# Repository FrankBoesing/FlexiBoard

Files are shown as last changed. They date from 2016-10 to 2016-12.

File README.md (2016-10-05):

# FlexiBoard

##Board for Teensy 3.2, 3.5, 3.6

https://forum.pjrc.com/threads/36869-T3-x-Flexiboard(-)

Link to board @ PCBs.io: https://pcbs.io/search?query=flexiboard
### License

<br />This work is licensed under a <a rel="license" href="http://creativecommons.org/licenses/by-sa/4.0/">Creative Commons Attribution-ShareAlike 4.0 International License</a>.

### Some Pictures
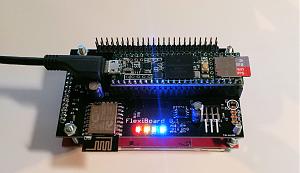
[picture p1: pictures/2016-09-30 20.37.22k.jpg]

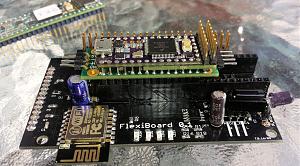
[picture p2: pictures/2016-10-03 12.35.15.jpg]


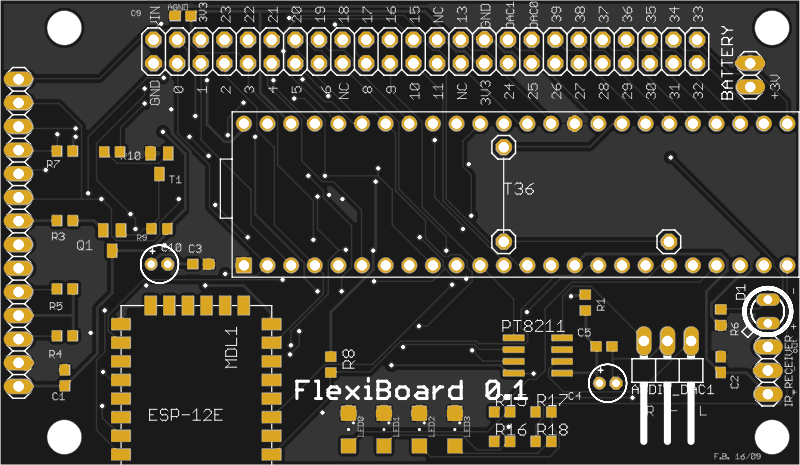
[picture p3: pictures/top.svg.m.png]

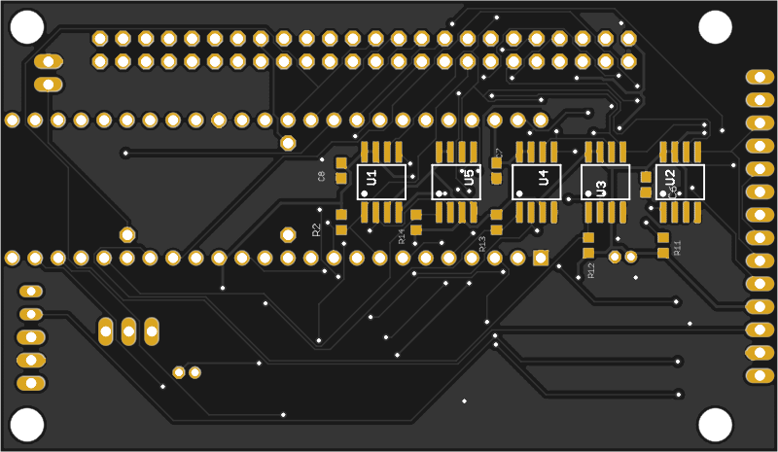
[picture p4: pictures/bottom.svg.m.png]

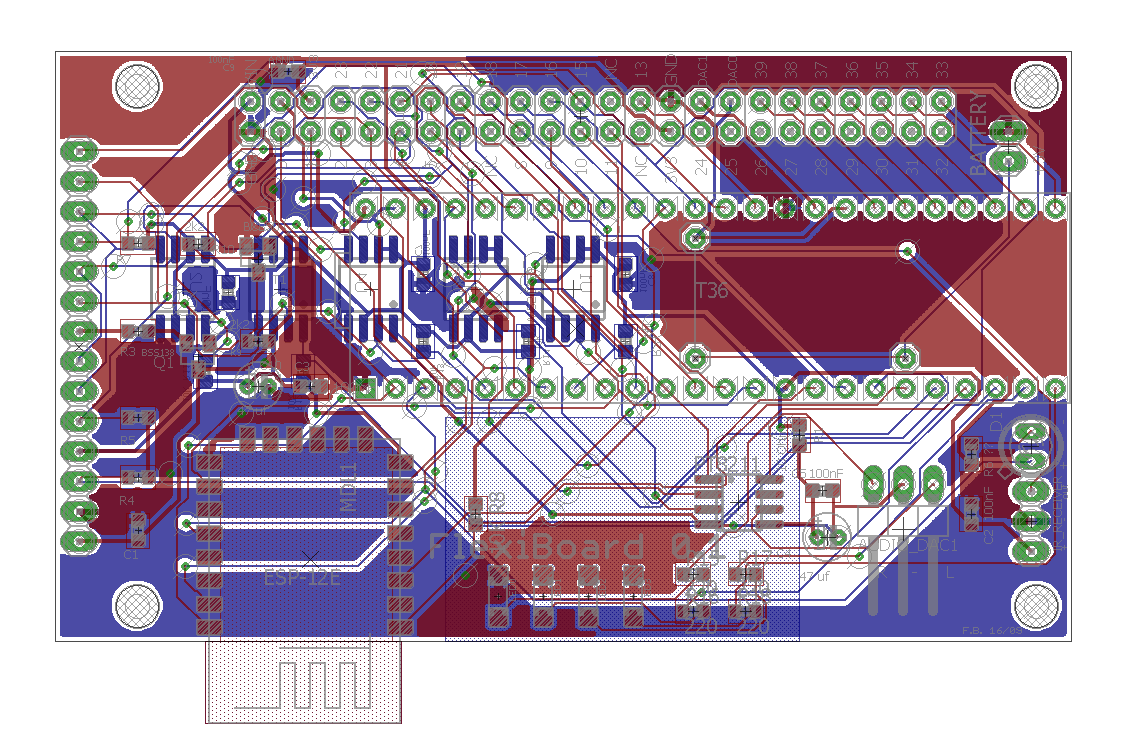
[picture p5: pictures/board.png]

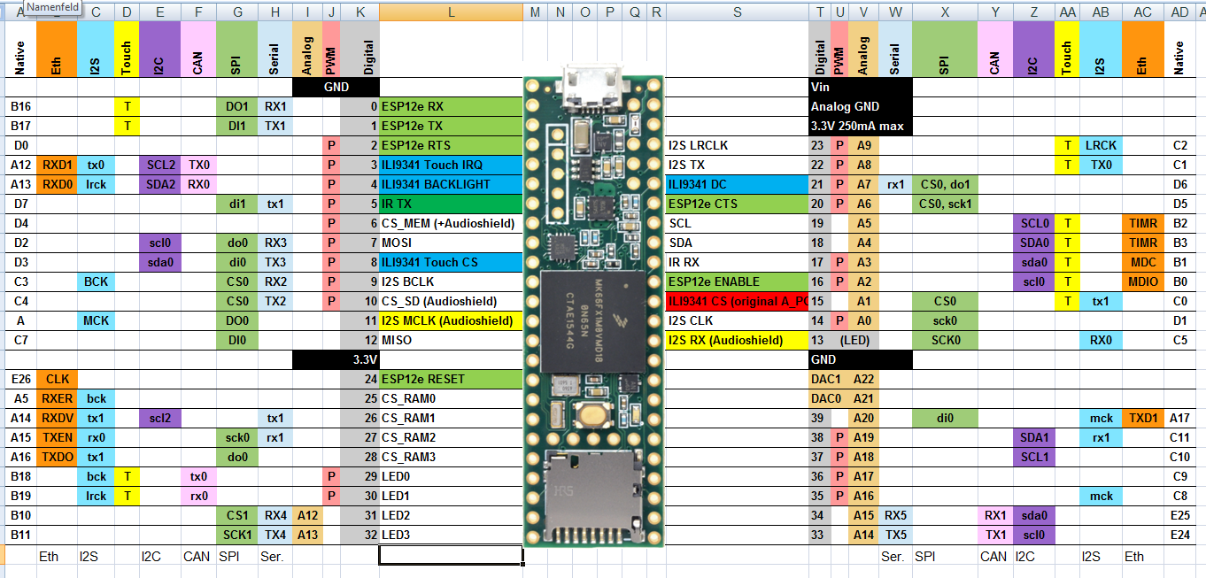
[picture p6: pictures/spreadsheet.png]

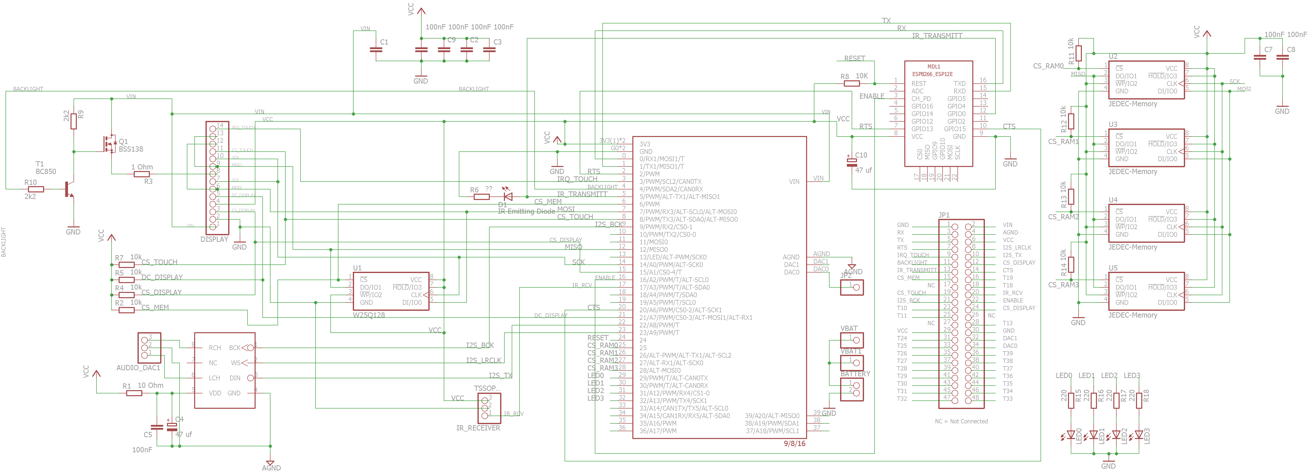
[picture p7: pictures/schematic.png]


## FLASH ESP FIRMWARE

### Flash size 32Mbit: 512KB+512KB
    boot_v1.2+.bin              0x00000
    user1.1024.new.2.bin        0x01000
    esp_init_data_default.bin   0x3fc000 (optional)
    blank.bin                   0x7e000 & 0x3fe000

## Flash Firmware

1. Extract the Firmware and Flash-Tool in extras/ESP8266/Firmware.zip

2. Start ESP8266Flasher.exe and configure it :

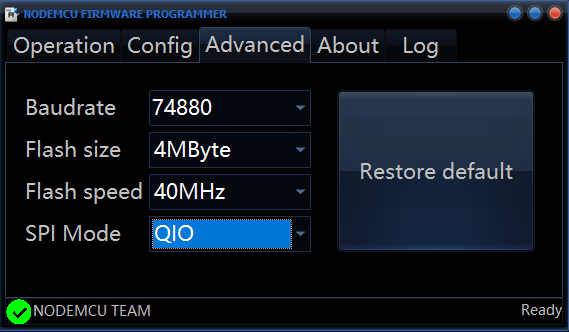
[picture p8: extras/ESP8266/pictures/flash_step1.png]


Select the files to upload (from the zip-file):

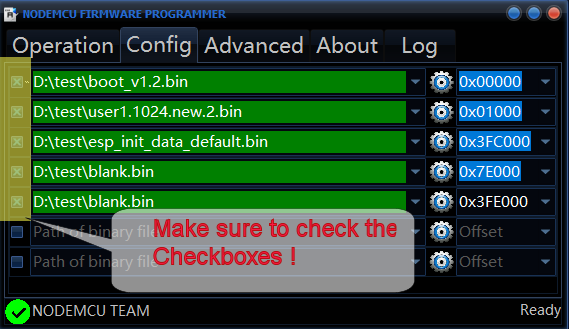
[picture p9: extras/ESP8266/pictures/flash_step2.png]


Load FlexiBoard_FlashESP8266.ino to the Teensy

Select the COM-Port:

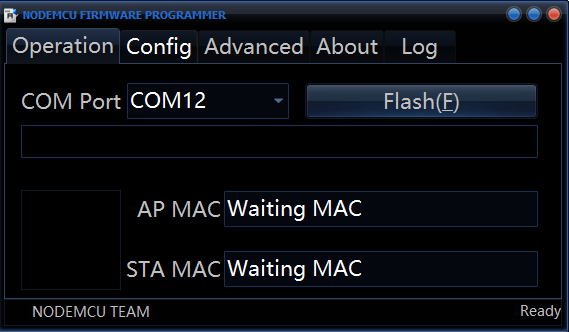
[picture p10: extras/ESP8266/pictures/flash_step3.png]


Reset the Teensy and click the "Flash" button

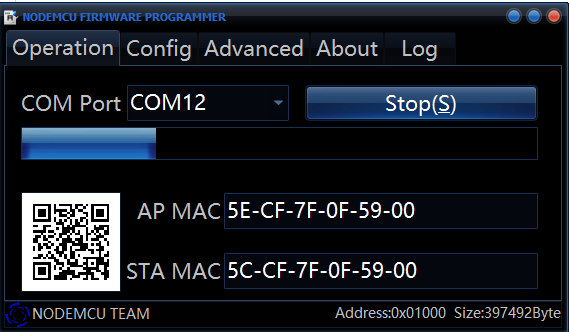
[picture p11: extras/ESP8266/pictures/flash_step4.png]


After that, you can run FlexiBoard_TalkToESP8266.ino and enter the following commands into the console to update the ESP8266-Firmware:

## Update Firmware

1.Start FlexiBoard_TalkToESP8266.ino example and select CR+LF as lineendings in the terminal.

2.Make sure the ESP is in sta or sta+ap mode

    AT+CWMODE=3
    OK

3.Make sure it got the ip address

    AT+CWJAP="YourSSID","YourWLANPassword"
    OK
    
    AT+CIFSR
    192.168.1.134

4.Let's update

    AT+CIUPDATE
    +CIPUPDATE:1    found server
    +CIPUPDATE:2    connect server
    +CIPUPDATE:3    got edition
    +CIPUPDATE:4    start start
    
    OK

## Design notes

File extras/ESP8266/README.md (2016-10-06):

#Using Arduino for ESP

- Upload the FlexiBoard_FlashESP8266 example to the Teensy

- Enter http://arduino.esp8266.com/stable/package_esp8266com_index.json into Additional Board Manager URLs field. 

- Open Boards Manager from Tools > Board menu and install esp8266 platform (and don't forget to select your ESP8266 board from Tools > Board menu after installation).

- Select the following options from the Arduino-Menu:

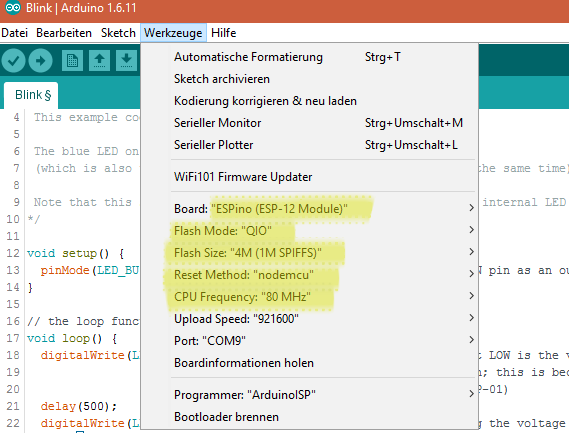
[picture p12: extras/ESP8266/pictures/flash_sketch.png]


- Try the BLINK-Example from the Examples / ESP8266 Menu

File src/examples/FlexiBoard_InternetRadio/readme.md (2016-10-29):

Minimal Internetradio
===

This is a minimal webradio. It is in no way complete.
In can play 44.1KHz - MP3 radio streams.

It works best, if you add (min) 2 pcs 23LC1024 RAMS (or more).
But i can be run with the Teensy 3.5/3.6 RAM only, too. 
In this case, 128KB internal RAM are used. This is a bit too less, so 
expect some problems, if your internet-connection is not good.

Currently, it connects to a German station - you may want to edit that, and use
a local station for a better connection.

Setup
===

For a better experience, edit _Serial1.c_ from the Teensy-core and set 
RX_BUFFER_SIZE     2048

Use the Example "TalkToESP" to setup the ESP:

First, restore the factory-settings:
- AT+RESTORE

Set station mode:
- AT+CWMODE_DEF=1

Store the connection to your WLAN
- AT+CWJAP_DEF ="SSID", "PASSWORD"

Additional libraries needed: 
https://github.com/FrankBoesing/Teensy-MP3

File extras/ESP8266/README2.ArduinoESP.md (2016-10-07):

Posted details here from :: https://forum.pjrc.com/threads/36869-T3-x-Flexiboard(-)?p=117701&viewfull=1#post117701

HOW TO GET ESP PROGRAMMED OTA WITH A very functional WEBSERVER THROUGH ARDUINO::
I'd say start with IDE 1.6.12 it works for me.

Get Server code from here: https://github.com/nailbuster/myWebServer
It says to get these two things to your sketchbook/libraries folder:
- TimeLib for ntp here: https://github.com/PaulStoffregen/Time
- Arduino Json here: https://github.com/bblanchon/ArduinoJson 

Get the ESP Arduino code from here: https://github.com/esp8266/Arduino

Use Boards Manager and the JSON from there: 
Boards manager link: http://arduino.esp8266.com/stable/pa...com_index.json 

By default OTA is OFF! - it won't show this used "ArduinoOTA"
Find this code on your machine where you put it in libraries and uncomment this line >> //#define ALLOW_IDEOTA
https://github.com/nailbuster/myWebServer/blob/master/myWebServer.h#L48
- OTA is "unsafe" so it is off by default :: - [there is a new scheme to password protect OTA updates - otherwise anyone who can see the WiFi name can program it.] :: https://github.com/esp8266/Arduino/blob/master/doc/ota_updates/readme.md#password-protection
- OTA requires PYTHON_2.7 to be installed ON THE PATH :: https://github.com/esp8266/Arduino/blob/master/doc/ota_updates/readme.md#application-example

If you do that and compile "sketchbook...\libraries\myWebServer\examples\myWe bServerSample" it should show those libraries like this::

- Using library ESP8266WiFi at version 1.0 in folder: C:\Users\YOU\AppData\Local\Arduino15\packages\esp8 266\hardware\esp8266\2.3.0\libraries\ESP8266WiFi 
- Using library ESP8266WebServer at version 1.0 in folder: C:\Users\YOU\AppData\Local\Arduino15\packages\esp8 266\hardware\esp8266\2.3.0\libraries\ESP8266WebSer ver 
- Using library ESP8266mDNS in folder: C:\Users\YOU\AppData\Local\Arduino15\packages\esp8 266\hardware\esp8266\2.3.0\libraries\ESP8266mDNS (legacy)
- Using library DNSServer at version 1.1.0 in folder: C:\Users\YOU\AppData\Local\Arduino15\packages\esp8 266\hardware\esp8266\2.3.0\libraries\DNSServer 
- Using library ArduinoOTA at version 1.0 in folder: C:\Users\YOU\AppData\Local\Arduino15\packages\esp8 266\hardware\esp8266\2.3.0\libraries\ArduinoOTA 
- Using library ArduinoJson at version 5.1.0 in folder: i:\tcode\libraries\ArduinoJson 
- Using library myWebServer at version 1.0.1 in folder: i:\tcode\libraries\myWebServer 
- Using library Time at version 1.5 in folder: i:\tcode\libraries\Time 

The first time upload you'll have to push over serially of course. 
From then on - if you don't add faulting code you can do OTA updates about 5 times faster than Serial. As noted I set up an ESP read pin that is set to indicate ABORT USER CODE (by Teensy or wire) and just allow ther server code to run and do OTA. It is easy to touch something (IN ERROR) and HANG an ESP because it is doing DISK and WIFI stuff - if you repower with that bit set - it will wait for a fresh OTA upload. I think this is on my GitHub too. << I could post my sketches but they are hacked to accommodate 4 different ESP's and their different configurations to the Teensy/onehorse_FC_3.2 units - after 6 months I don't under stand them again myself yet. And they would not match the Flexiboard - but I might post something as it was quite fun and usable.>>

>> For starters I would suggest using 4MB with 3 MB SPIFFS - 1MB for code is good, 3MB for SPIFFS is better. My sketch is 311KB. Using of near HALF of 1MB still allows OTA FLASH - you can change later if you want that much code. This WEBSERVER library runs all HTML pages for the server from SPIFFS - You can Read Write other data there too when you don't need to put it in FLASH - the upload is smaller faster.

Get your Server IP address and his :: 192.168.1. _??_ /wifisetup.html, there is a .gz file there it runs from, you can NAME the device and that will show on the IDE then.
<<Yes the server has code to perform GZ decompress to some degree on files to run them! Details on the server github - I asked a question in an ISSUE>>

- WARNING - WARNING - WARNING !!!!
- I just wiped my 3MB SPIFFS DATA - when you enter the IDE ALWAYS CHECK the TOOLS :: SPIFFS size and other params - the IDE will often not remember some of those CRITICAL things properly across board changes!!!!!
- I just found this out the hard way for the first time - so that lets me show the details above because my ESP is TRASHED - 512K Code and 64K SPIFFS is the DEFAULT !!!!!
- WARNING - WARNING - WARNING !!!!
So I lost my SPIFFS data - my network configuration setting and I cannot OTA upload because 512MB cannot fit two copies of the 311K sketch !!!!
I'll have to get the details right to T_3.2 proxy upload again from my hacked sketch ...

ONE MORE MISSING PIECE :: 
- You can just transfer files over FTP once the server is running - THAT IS WAY COOL!!
- You may want SPIFFS IMAGE data on your device 
My github refers to this :: you make a folder image and then upload the data to it. 
https://github.com/esp8266/arduino-esp8266fs-plugin/releases/tag/0.2.0

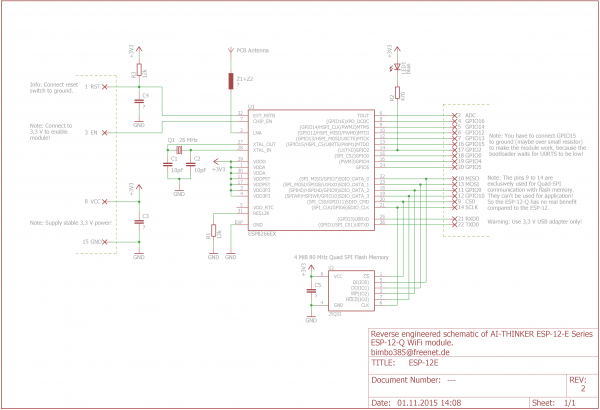
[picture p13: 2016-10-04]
extras/ESP8266/schematic_esp-12e.png

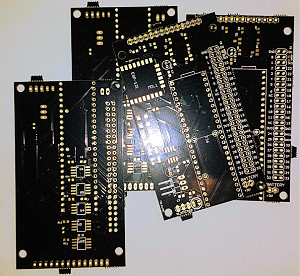
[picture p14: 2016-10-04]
pictures/2016-10-01 16.12.59k.png

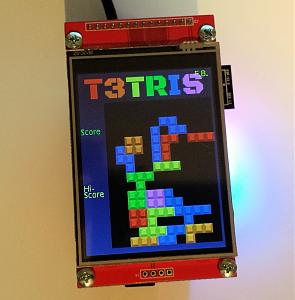
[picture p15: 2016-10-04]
pictures/2016-09-30 20.38.55k.jpg

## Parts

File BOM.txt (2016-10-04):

Partlist

Part        Value              Device                    Package

Mount all:
C1          100nF              C-EUC0603                 C0603
C2          100nF              C-EUC0603                 C0603
C3          100nF              C-EUC0603                 C0603
C5          100nF              C-EUC0603                 C0603
C6          100nF              C-EUC0603                 C0603
C7          100nF              C-EUC0603                 C0603
C8          100nF              C-EUC0603                 C0603
C9          100nF              C-EUC0603                 C0603

WLAN
=====
ESP8266-ESP12E
C10         220 uf             CPOL-EUE1.8-4             E1,8-4
R8          10K                R-EU_R0603                R0603

AUDIO
=======
PT8211      PT8211SO8          PT8211SO8                 SO8
AUDIO_DAC1                     PINHD-1X3/90              1X03/90
C4          47 uf              CPOL-EUE1.8-4             E1,8-4
R1          10 Ohm             R-EU_R0603                R0603

MEMORY
======
For example RAM 23LC1024 or Flash W25Q128

U1          JEDEC-Memory       				 SOIC-8
U2          JEDEC-Memory
U3          JEDEC-Memory
U4          JEDEC-Memory
U5          JEDEC-Memory
R2          10k                R-EU_R0603                R0603
R11         10k                R-EU_R0603                R0603
R12         10k                R-EU_R0603                R0603
R13         10k                R-EU_R0603                R0603
R14         10k                R-EU_R0603                R0603

IR RECEIVE
==========
For example TSOP1136 or many others.
IR_RECEIVER TSOP..             PINHD-1X3                 1X03

IR SEND
==========
D1          IR Emitting Diode  ????                      ????
R6          100                R-EU_R0603                R0603

VBAT:
=====
VBAT                           PINHD-1X1                 1X01
VBAT1                          PINHD-1X1                 1X01
BATTERY                        PINHD-1X2                 1X02

LED:
======

LED0                           LEDSML1206                SML1206
LED1                           LEDSML1206                SML1206
LED2                           LEDSML1206                SML1206
LED3                           LEDSML1206                SML1206
R15         330 Ohm            R-EU_R0603                R0603
R16         330 Ohm            R-EU_R0603                R0603
R17         330 Ohm            R-EU_R0603                R0603
R18         330 Ohm            R-EU_R0603                R0603

DISPLAY
=======
ILI9341 with touch

T1          BC850              BC850                     SOT23
Q1          BSS138             BSS123                    SOT23
R3          10 Ohm             R-EU_R0603                R0603
R4          10k                R-EU_R0603                R0603

R5          10k                R-EU_R0603                R0603

R7          10k                R-EU_R0603                R0603
R9          1k                 R-EU_R0603                R0603
R10         1k                 R-EU_R0603                R0603
DISPLAY                        PINHD-1X14                1X14

JP1                            PINHD-2X24                2X24

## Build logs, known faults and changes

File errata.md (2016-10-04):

#Errata:
- Wrong location for Teensy 3.1/3.2 VBAT/DAC0 Pins (still possible to use them with a bit fiddling.. or use Teesy 3.5/3.6)
- Due to an error, pins 24-32 are not routed to the 48-Pin-connector :-( FIX: Patch them on the backside.
- Limited IR-Send power, but works for distances ~2m. For more power, add a (extern) transistor.
- The connector for the IR-Receiver is + - OUT, but most IR -Receivers use - + OUT Fix: Do not mount directly and use a cable

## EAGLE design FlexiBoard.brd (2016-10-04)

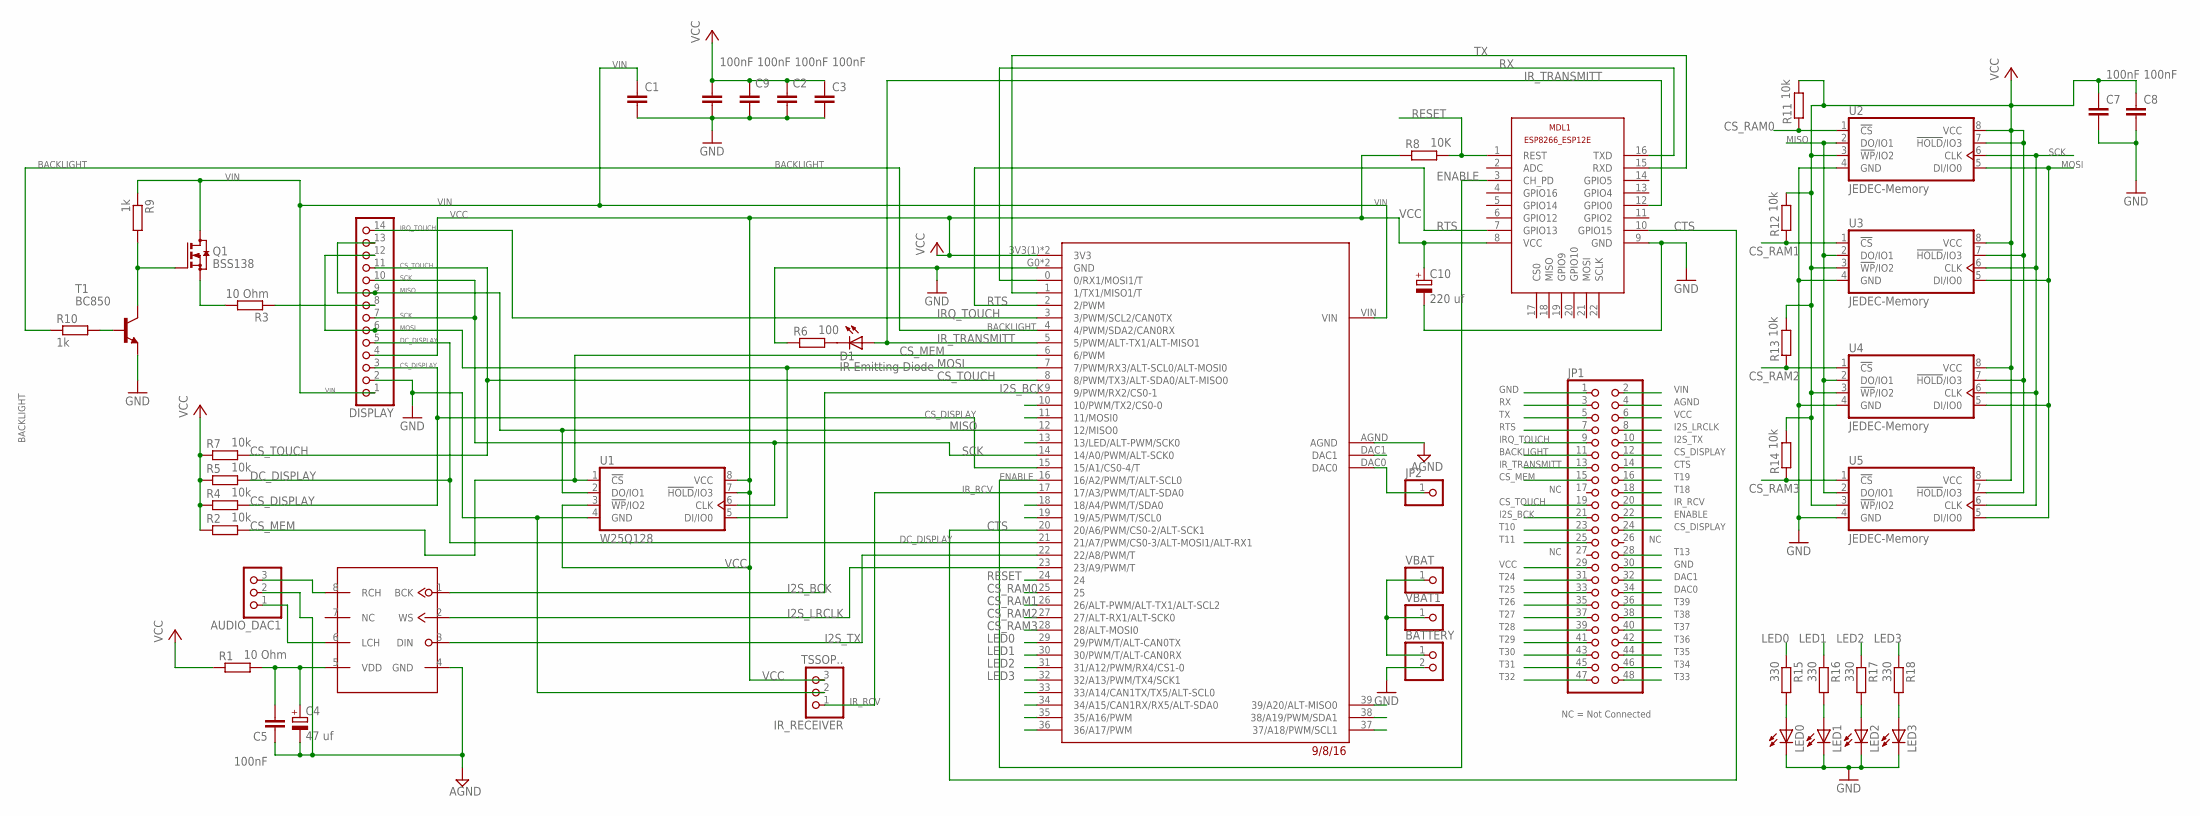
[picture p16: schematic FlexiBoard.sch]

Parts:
AUDIO_DAC1: PINHD-1X3/90; 1X03/90
BATTERY: PINHD-1X2; 1X02
C1, C2, C3, C5, C6, C7, C8, C9: 100nF; C0603
C4: 47 uf; E1,8-4
C10: 220 uf; E1,8-4
D1: IR Emitting Diode; SFH482
DISPLAY: PINHD-1X14; 1X14
IR_RECEIVER: TSSOP..; 1X03
JP1: PINHD-2X24; 2X24
JP2: PINHD-1X1; 1X01
LED0, LED1, LED2, LED3: LEDSML1206; SML1206
MDL1: ESP8266-12EESP8266-ESP12E; ESP8266-ESP12E
PT8211: PT8211SO8; SO8
Q1: BSS138; SOT23
R1, R3: 10 Ohm; R0603
R2, R4, R5, R7, R11, R12, R13, R14: 10k; R0603
R6: 100; R0603
R8: 10K; R0603
R9, R10: 1k; R0603
R15, R16, R17, R18: 330; R0603
T1: BC850; SOT23
U1: W25Q128; SO08-SS
U2, U3, U4, U5: JEDEC-Memory; SO08-SS
U$2: TEENSY36_OUTERPINS; T36_OUTER_PINS
VBAT, VBAT1: PINHD-1X1; 1X01

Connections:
AGND: AUDIO_DAC1.2, C4.-, C5.1, JP1.4, PT8211.4 (GND), U$2.AGND
BACKLIGHT: JP1.11, R10.1, U$2.4 (4/PWM/SDA2/CAN0RX)
CS_DISPLAY: DISPLAY.3, JP1.12, JP1.24, R4.2, U$2.15 (15/A1/CS0-4/T)
CS_MEM: JP1.15, R2.2, U1.1 (!CS!), U$2.6 (6/PWM)
CS_RAM0: R11.1, U2.1 (!CS!), U$2.25
CS_RAM1: R12.1, U3.1 (!CS!), U$2.26 (26/ALT-PWM/ALT-TX1/ALT-SCL2)
CS_RAM2: R13.1, U4.1 (!CS!), U$2.27 (27/ALT-RX1/ALT-SCK0)
CS_RAM3: R14.1, U5.1 (!CS!), U$2.28 (28/ALT-MOSI0)
CS_TOUCH: DISPLAY.11, JP1.19, R7.2, U$2.8 (8/PWM/TX3/ALT-SDA0/ALT-MISO0)
CTS: JP1.14, MDL1.10 (GPIO15), U$2.20 (20/A6/PWM/CS0-2/ALT-SCK1)
DAC0: JP1.34, JP2.1, U$2.DAC0
DAC1: JP1.32, U$2.DAC1
DC_DISPLAY: DISPLAY.5, R5.2, U$2.21 (21/A7/PWM/CS0-3/ALT-MOSI1/ALT-RX1)
ENABLE: JP1.22, MDL1.3 (CH_PD), U$2.16 (16/A2/PWM/T/ALT-SCL0)
GND: BATTERY.2, C1.2, C2.2, C3.2, C6.2, C7.2, C8.2, C9.2, C10.-, DISPLAY.2, IR_RECEIVER.2, JP1.1, JP1.30, LED0.C, LED1.C, LED2.C, LED3.C, MDL1.9 (GND), R6.1, T1.2 (E), U1.4 (GND), U2.4 (GND), U3.4 (GND), U4.4 (GND), U5.4 (GND), U$2.G0 (GND), U$2.G2 (GND)
I2S_BCK: JP1.21, PT8211.1 (BCK), U$2.9 (9/PWM/RX2/CS0-1)
I2S_LRCLK: JP1.8, PT8211.2 (WS), U$2.23 (23/A9/PWM/T)
I2S_TX: JP1.10, PT8211.3 (DIN), U$2.22 (22/A8/PWM/T)
IRQ_TOUCH: DISPLAY.14, JP1.9, U$2.3 (3/PWM/SCL2/CAN0TX)
IR_RCV: IR_RECEIVER.1, JP1.20, U$2.17 (17/A3/PWM/T/ALT-SDA0)
IR_TRANSMITT: D1.A, JP1.13, MDL1.12 (GPIO0), U$2.5 (5/PWM/ALT-TX1/ALT-MISO1)
LED0: R15.1, U$2.29 (29/PWM/T/ALT-CAN0TX)
LED1: R16.1, U$2.30 (30/PWM/T/ALT-CAN0RX)
LED2: R17.1, U$2.31 (31/A12/PWM/RX4/CS1-0)
LED3: R18.1, U$2.32 (32/A13/PWM/TX4/SCK1)
LED-DISPLAY: DISPLAY.8, R3.1
MISO: DISPLAY.9, DISPLAY.13, U1.2 (DO/IO1), U2.2 (DO/IO1), U3.2 (DO/IO1), U4.2 (DO/IO1), U5.2 (DO/IO1), U$2.12 (12/MISO0)
MOSI: DISPLAY.6, DISPLAY.12, U1.5 (DI/IO0), U2.5 (DI/IO0), U3.5 (DI/IO0), U4.5 (DI/IO0), U5.5 (DI/IO0), U$2.7 (7/PWM/RX3/ALT-SCL0/ALT-MOSI0)
unnamed: AUDIO_DAC1.1, PT8211.6 (LCH)
unnamed: Q1.2 (S), R3.2
unnamed: BATTERY.1, VBAT.1, VBAT1.1
unnamed: LED0.A, R15.2
unnamed: Q1.1 (G), R9.2, T1.3 (C)
unnamed: LED1.A, R16.2
unnamed: AUDIO_DAC1.3, PT8211.8 (RCH)
unnamed: R10.2, T1.1 (B)
unnamed: D1.K (C), R6.2
unnamed: LED2.A, R17.2
unnamed: LED3.A, R18.2
RESET: MDL1.1 (REST), R8.2, U$2.24
RTS: JP1.7, MDL1.7 (GPIO13), U$2.2 (2/PWM)
RX: JP1.3, MDL1.16 (TXD), U$2.0 (0/RX1/MOSI1/T)
SCK: DISPLAY.7, DISPLAY.10, U1.6 (CLK), U2.6 (CLK), U3.6 (CLK), U4.6 (CLK), U5.6 (CLK), U$2.14 (14/A0/PWM/ALT-SCK0)
T10: JP1.23, U$2.10 (10/PWM/TX2/CS0-0)
T11: JP1.25, U$2.11 (11/MOSI0)
T13: JP1.28, U$2.13 (13/LED/ALT-PWM/SCK0)
T18: JP1.18, U$2.18 (18/A4/PWM/T/SDA0)
T19: JP1.16, U$2.19 (19/A5/PWM/T/SCL0)
T24: JP1.31
T25: JP1.33
T26: JP1.35
T27: JP1.37
T28: JP1.39
T29: JP1.41
T30: JP1.43
T31: JP1.45
T32: JP1.47
T33: JP1.48, U$2.33 (33/A14/CAN1TX/TX5/ALT-SCL0)
T34: JP1.46, U$2.34 (34/A15/CAN1RX/RX5/ALT-SDA0)
T35: JP1.44, U$2.35 (35/A16/PWM)
T36: JP1.42, U$2.36 (36/A17/PWM)
T37: JP1.40, U$2.37 (37/A18/PWM/SCL1)
T38: JP1.38, U$2.38 (38/A19/PWM/SDA1)
T39: JP1.36, U$2.39 (39/A20/ALT-MISO0)
TX: JP1.5, MDL1.15 (RXD), U$2.1 (1/TX1/MISO1/T)
VCC: C2.1, C3.1, C6.1, C7.1, C8.1, C9.1, C10.+, DISPLAY.4, IR_RECEIVER.3, JP1.6, JP1.29, MDL1.8 (VCC), R1.1, R2.1, R4.1, R5.1, R7.1, R8.1, R11.2, R12.2, R13.2, R14.2, U1.3 (!WP!/IO2), U1.7 (!HOLD!/IO3), U1.8 (VCC), U2.3 (!WP!/IO2), U2.7 (!HOLD!/IO3), U2.8 (VCC), U3.3 (!WP!/IO2), U3.7 (!HOLD!/IO3), U3.8 (VCC), U4.3 (!WP!/IO2), U4.7 (!HOLD!/IO3), U4.8 (VCC), U5.3 (!WP!/IO2), U5.7 (!HOLD!/IO3), U5.8 (VCC), U$2.3V3(1) (3V3), U$2.3V3(3) (3V3)
VDD: C4.+, C5.2, PT8211.5 (VDD), R1.2
VIN: C1.1, DISPLAY.1, JP1.2, Q1.3 (D), R9.1, U$2.VIN

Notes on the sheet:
NC = Not Connected

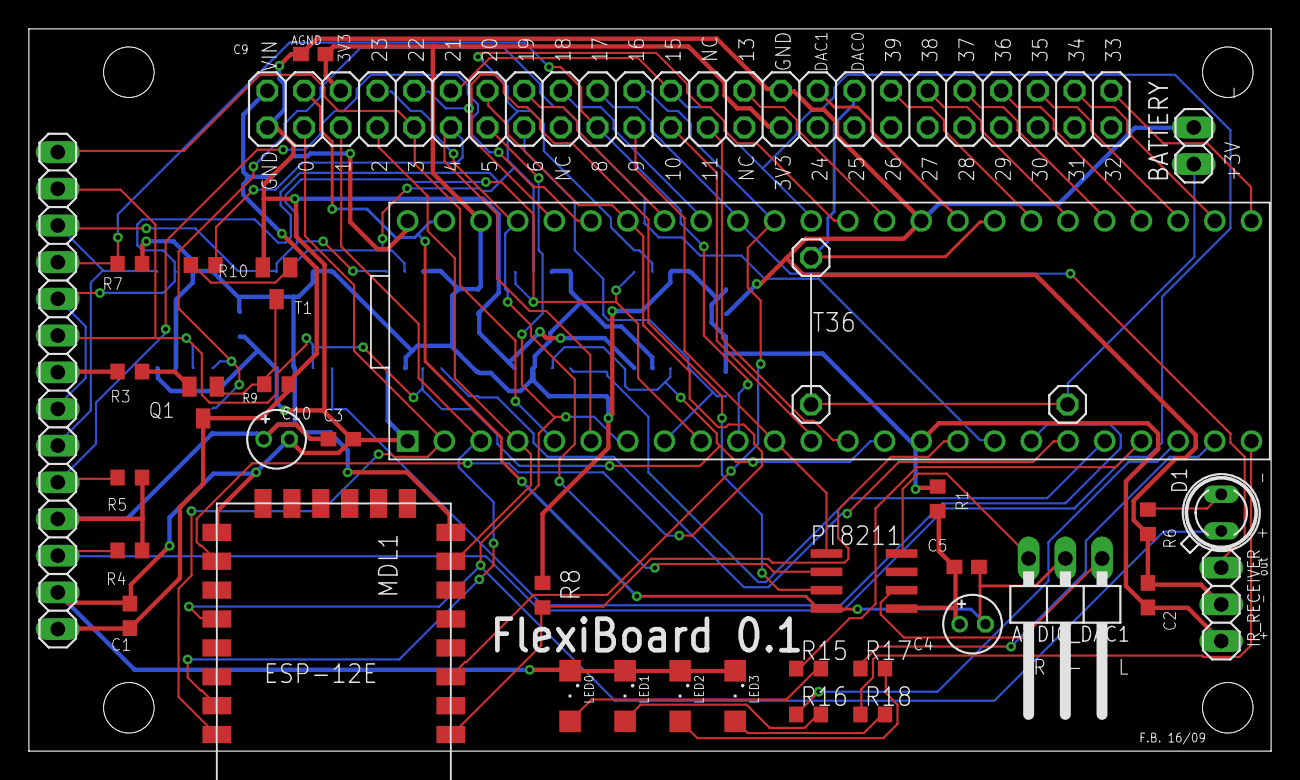
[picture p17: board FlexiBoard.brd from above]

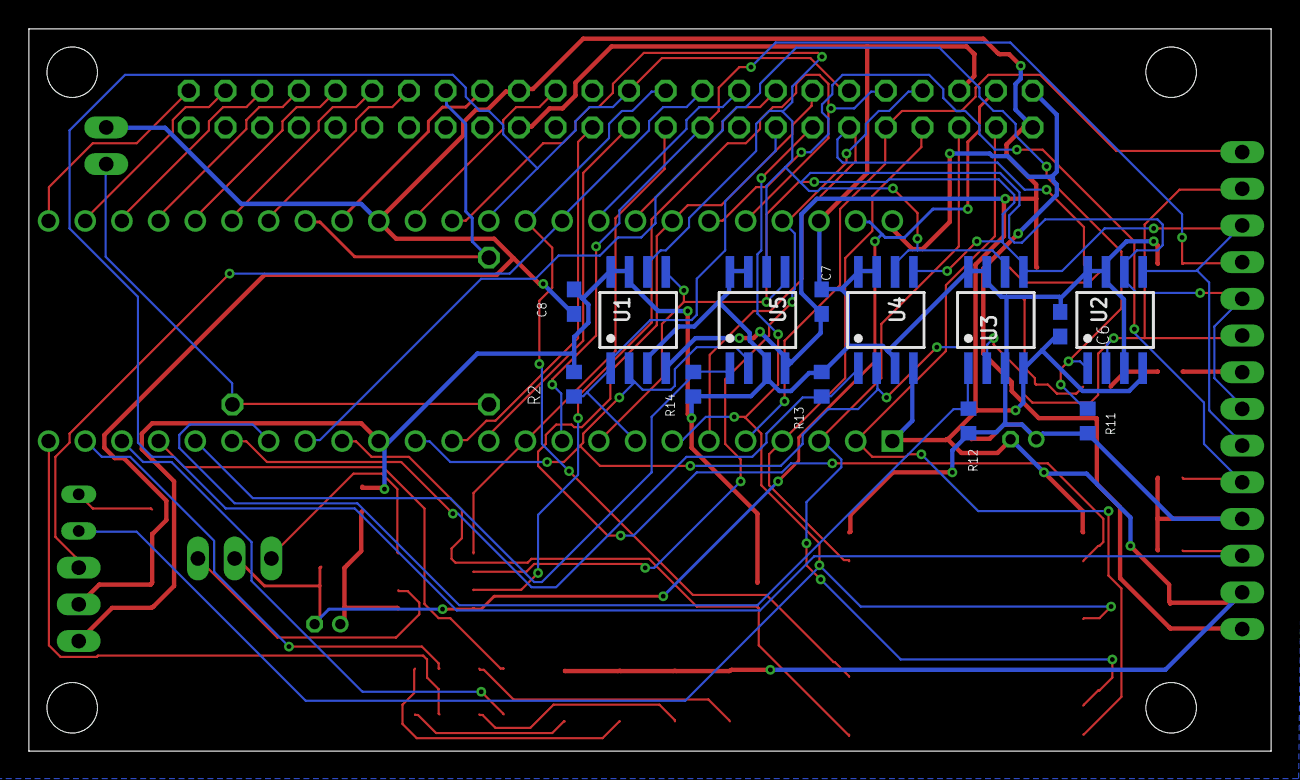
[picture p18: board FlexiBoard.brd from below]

Board: 2 copper layers, 86.0 x 50.0 mm, 51 parts (13 on the bottom side), 59 nets.

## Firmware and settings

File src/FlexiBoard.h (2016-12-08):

#ifndef _FlexiBoard_h_
#define _FlexiBoard_h_

/* ============================================================================================================== */
/* Edit the configuration of the FlexiBoard here:                                                                 */

#define HAVE_PT8211		1 	// 0= not available / 1=available
#define HAVE_ILI9341	1	// 0= not available / 1=available

#define HAVE_ESP12E		1	// 0= not available / 1=available
#define HAVE_RTL8710	0	// 0= not available / 1=available

#define HAVE_IR_SND	1	// 0= not available / 1=available
#define HAVE_IR_RCV	1	// 0= not available / 1=available

#define HAVE_FLASH	1	// 0= not available / 1=available	(U0 is either FLASH or RAM!)
#define HAVE_RAM0	0	// 0= not available / 1=available	(U0 is either FLASH or RAM!)
#define HAVE_RAM1	1	// 0= not available / 1=available
#define HAVE_RAM2	1	// 0= not available / 1=available
#define HAVE_RAM3	1	// 0= not available / 1=available
#define HAVE_RAM4	1	// 0= not available / 1=available
#define RAM_SIZE	(128 * 1024)	// 23LC1024 = 128KB

#define HAVE_LED0	1	// 0= not available / 1=available
#define HAVE_LED1	1	// 0= not available / 1=available
#define HAVE_LED2	1	// 0= not available / 1=available
#define HAVE_LED3	1	// 0= not available / 1=available


/* ============================================================================================================== */
/* DON'T Edit below this line                                                                                     */

#if HAVE_FLASH && HAVE_RAM0
#error FlexiBoard.h: Configuration error!!!
#endif

#define SCK  14
#define MISO 12
#define MOSI  7

#define LEDT LED_BUILTIN   //Teensy-LED

#if HAVE_LED0
#define LED0 29   //red
#else
#define LED0 255
#endif

#if HAVE_LED1
#define LED1 30   //orange
#else
#define LED1 255
#endif

#if HAVE_LED2
#define LED2 31   //green
#else
#define LED2 255
#endif

#if HAVE_LED3
#define LED3 32   //blue
#else
#define LED3 255
#endif

const uint8_t ledArr[] = { LED0, LED1, LED2, LED3 };
#define SETLED(_led,_onoff) { if ( (_led < sizeof(ledArr) ) && ledArr[_led]<255) digitalWriteFast(ledArr[_led],_onoff); }

#define TFT_BACKLIGHT   4
#define TFT_TOUCH_CS    8
#define TFT_TOUCH_INT   3
#define TFT_DC          21
#define TFT_CS          15
#define TFT_RST         255  // 255 = unused, connected to 3.3V
#define TFT_SCLK        SCK
#define TFT_MOSI        MOSI
#define TFT_MISO        MISO

#define MEM0_CS         6
#define MEM1_CS         25
#define MEM2_CS         26
#define MEM3_CS         27
#define MEM4_CS         28

uint8_t ramArrCS[] = {
#if HAVE_FLASH
#define FLASH_CS		MEM0_CS
#elif HAVE_RAM0
	MEM0_CS,
#endif
#if HAVE_RAM1
	MEM1_CS,
#endif
#if HAVE_RAM2
	MEM2_CS,
#endif
#if HAVE_RAM3
	MEM3_CS,
#endif
#if HAVE_RAM4
	MEM4_CS
#endif
	};

#define HAVE_RAM 		(defined(HAVE_RAM0) || defined(HAVE_RAM1) || defined(HAVE_RAM2) ||\
						 defined(HAVE_RAM3) || defined(HAVE_RAM4))
#define NUM_RAMS		(sizeof(ramArrCS))
#define RAM_SIZE_TOTAL	(NUM_RAMS * RAM_SIZE)


#define IR_RCV          17
#define IR_SND          5  //Shared with WLAN_GPIO0 !

#define WLAN_SERIAL     Serial1
#define WLAN_SERIAL_BAUD_INIT 74880
#define WLAN_SERIAL_BAUD 115200
#define WLAN_RESET      24
#define WLAN_ENABLE     16  //CH_PD
#define WLAN_CTS        20  //GPIO15
#define WLAN_RTS        2   //GPIO13
#define WLAN_GPIO0      5   //Shared with IR_SND !
#define WLAN_GPIO13     WLAN_RTS
#define WLAN_GPIO15     WLAN_CTS


void setBacklight(float brightness) { // ( range from 0 to 1.0 )
#if HAVE_ILI9341
  int b;

  b = 256 - roundf(256.0f * brightness);

  if (b < 0) b = 0;
  if (b > 256) b = 256;
  pinMode(TFT_BACKLIGHT, OUTPUT);
  analogWrite(TFT_BACKLIGHT, b); //(0=Max, 256=MIN)
#endif
}

bool resetWLAN() {
#if HAVE_ESP12E
  WLAN_SERIAL.begin(WLAN_SERIAL_BAUD);

  pinMode(WLAN_RESET, OUTPUT);
  pinMode(WLAN_ENABLE, OUTPUT);
  pinMode(WLAN_CTS, OUTPUT);
  pinMode(WLAN_GPIO0, OUTPUT);

  digitalWrite(WLAN_CTS, LOW);
  digitalWrite(WLAN_ENABLE, LOW);

  //Reset ESP
  digitalWrite(WLAN_RESET, LOW);
  delay(15);
  digitalWrite(WLAN_ENABLE, HIGH);
  digitalWrite(WLAN_RESET, HIGH);

  //The ESP - Bootloader waits for  HIGH on WLAN_GPIO0
  digitalWrite(WLAN_GPIO0, HIGH);

  bool ret = WLAN_SERIAL.findUntil("ready","");

  //GPIO0 ist not needed anymore:
  pinMode(WLAN_GPIO0, INPUT);

  //Disable all used pins if no response from ESP
  if (!ret) {
    pinMode(WLAN_RESET, INPUT);
    pinMode(WLAN_ENABLE, INPUT);
    pinMode(WLAN_CTS, INPUT);
  }

  return ret;
#endif
}



void initLEDs(void) {
  if (LED0<255) pinMode(LED0, OUTPUT);
  if (LED1<255) pinMode(LED1, OUTPUT);
  if (LED2<255) pinMode(LED2, OUTPUT);
  if (LED3<255) pinMode(LED3, OUTPUT);
}


void initMEM() {
#if HAVE_FLASH
 pinMode(MEM0_CS, OUTPUT); digitalWriteFast(MEM0_CS, HIGH);
#endif 
 for (unsigned i=0; i<NUM_RAMS; i++) {
	pinMode(ramArrCS[i], OUTPUT); digitalWriteFast(ramArrCS[i], HIGH);
 }
}

#endif

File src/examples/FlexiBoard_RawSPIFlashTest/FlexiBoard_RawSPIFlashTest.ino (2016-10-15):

// RawHardwareTest - Check if a SPI Flash chip is compatible
// with SerialFlash by performing many read and write tests
// to its memory.
//
// The chip should be fully erased before running this test.
// Use the EraseEverything to do a (slow) full chip erase.
//
// Normally you should NOT access the flash memory directly,
// as this test program does.  You should create files and
// read and write the files.  File creation allocates space
// with program & erase boundaries within the chip, to allow
// reading from any other files while a file is busy writing
// or erasing (if created as erasable).
//
// If you discover an incompatible chip, please report it here:
// https://github.com/PaulStoffregen/SerialFlash/issues
// You MUST post the complete output of this program, and
// the exact part number and manufacturer of the chip.


// Modified for FlexiBoard

#include <SerialFlash.h>
#include <SPI.h>
#include <FlexiBoard.h>

const int FlashChipSelect = MEM0_CS; // digital pin for flash chip CS pin


SerialFlashFile file;

const unsigned long testIncrement = 4096;

void setup() {

  SPI.setSCK(SCK);
  SPI.setMOSI(MOSI);
  SPI.setMOSI(MISO);

  Serial.begin(9600);

  while (!Serial) ;
  delay(100);

  Serial.println("Raw SerialFlash Hardware Test");
  SerialFlash.begin(FlashChipSelect);

  if (test()) {
    Serial.println();
    Serial.println("All Tests Passed  :-)");
    Serial.println();
    Serial.println("Test data was written to your chip.  You must run");
    Serial.println("EraseEverything before using this chip for files.");
  } else {
    Serial.println();
    Serial.println("Tests Failed  :{");
    Serial.println();
    Serial.println("The flash chip may be left in an improper state.");
    Serial.println("You might need to power cycle to return to normal.");
  }
}


bool test() {
  unsigned char buf[256], sig[256], buf2[8];
  unsigned long address, count, chipsize, blocksize;
  unsigned long usec;
  bool first;

  // Read the chip identification
  Serial.println();
  Serial.println("Read Chip Identification:");
  SerialFlash.readID(buf);
  Serial.print("  JEDEC ID:     ");
  Serial.print(buf[0], HEX);
  Serial.print(" ");
  Serial.print(buf[1], HEX);
  Serial.print(" ");
  Serial.println(buf[2], HEX);
  Serial.print("  Part Nummber: ");
  Serial.println(id2chip(buf));
  Serial.print("  Memory Size:  ");
  chipsize = SerialFlash.capacity(buf);
  Serial.print(chipsize);
  Serial.println(" bytes");
  if (chipsize == 0) return false;
  Serial.print("  Block Size:   ");
  blocksize = SerialFlash.blockSize();
  Serial.print(blocksize);
  Serial.println(" bytes");


  // Read the entire chip.  Every test location must be
  // erased, or have a previously tested signature
  Serial.println();
  Serial.println("Reading Chip...");
  memset(buf, 0, sizeof(buf));
  memset(sig, 0, sizeof(sig));
  memset(buf2, 0, sizeof(buf2));
  address = 0;
  count = 0;
  first = true;
  while (address < chipsize) {
    SerialFlash.read(address, buf, 8);
    //Serial.print("  addr = ");
    //Serial.print(address, HEX);
    //Serial.print(", data = ");
    //printbuf(buf, 8);
    create_signature(address, sig);
    if (is_erased(buf, 8) == false) {
      if (equal_signatures(buf, sig) == false) {
        Serial.print("  Previous data found at address ");
        Serial.println(address);
        Serial.println("  You must fully erase the chip before this test");
        Serial.print("  found this: ");
        printbuf(buf, 8);
        Serial.print("     correct: ");
        printbuf(sig, 8);
        return false;
      }
    } else {
      count = count + 1; // number of blank signatures
    }
    if (first) {
      address = address + (testIncrement - 8);
      first = false;
    } else {
      address = address + 8;
      first = true;
    }
  }


  // Write any signatures that were blank on the original check
  if (count > 0) {
    Serial.println();
    Serial.print("Writing ");
    Serial.print(count);
    Serial.println(" signatures");
    memset(buf, 0, sizeof(buf));
    memset(sig, 0, sizeof(sig));
    memset(buf2, 0, sizeof(buf2));
    address = 0;
    first = true;
    while (address < chipsize) {
      SerialFlash.read(address, buf, 8);
      if (is_erased(buf, 8)) {
        create_signature(address, sig);
        //Serial.printf("write %08X: data: ", address);
        //printbuf(sig, 8);
        SerialFlash.write(address, sig, 8);
        while (!SerialFlash.ready()) ; // wait
        SerialFlash.read(address, buf, 8);
        if (equal_signatures(buf, sig) == false) {
          Serial.print("  error writing signature at ");
          Serial.println(address);
          Serial.print("  Read this: ");
          printbuf(buf, 8);
          Serial.print("  Expected:  ");
          printbuf(sig, 8);
          return false;
        }
      }
      if (first) {
        address = address + (testIncrement - 8);
        first = false;
      } else {
        address = address + 8;
        first = true;
      }
    }
  } else {
    Serial.println("  all signatures present from prior tests");
  }


  // Read all the signatures again, just to be sure
  // checks prior writing didn't corrupt any other data
  Serial.println();
  Serial.println("Double Checking All Signatures:");
  memset(buf, 0, sizeof(buf));
  memset(sig, 0, sizeof(sig));
  memset(buf2, 0, sizeof(buf2));
  count = 0;
  address = 0;
  first = true;
  while (address < chipsize) {
    SerialFlash.read(address, buf, 8);
    create_signature(address, sig);
    if (equal_signatures(buf, sig) == false) {
      Serial.print("  error in signature at ");
      Serial.println(address);
      Serial.print("  Read this: ");
      printbuf(buf, 8);
      Serial.print("  Expected:  ");
      printbuf(sig, 8);
      return false;
    }
    count = count + 1;
    if (first) {
      address = address + (testIncrement - 8);
      first = false;
    } else {
      address = address + 8;
      first = true;
    }
  }
  Serial.print("  all ");
  Serial.print(count);
  Serial.println(" signatures read ok");


  // Read pairs of adjacent signatures
  // check read works across boundaries
  Serial.println();
  Serial.println("Checking Signature Pairs");
  memset(buf, 0, sizeof(buf));
  memset(sig, 0, sizeof(sig));
  memset(buf2, 0, sizeof(buf2));
  count = 0;
  address = testIncrement - 8;
  first = true;
  while (address < chipsize - 8) {
    SerialFlash.read(address, buf, 16);
    create_signature(address, sig);
    create_signature(address + 8, sig + 8);
    if (memcmp(buf, sig, 16) != 0) {
      Serial.print("  error in signature pair at ");
      Serial.println(address);
      Serial.print("  Read this: ");
      printbuf(buf, 16);
      Serial.print("  Expected:  ");
      printbuf(sig, 16);
      return false;
    }
    count = count + 1;
    address = address + testIncrement;
  }
  Serial.print("  all ");
  Serial.print(count);
  Serial.println(" signature pairs read ok");


  // Write data and read while write in progress
  Serial.println();
  Serial.println("Checking Read-While-Write (Program Suspend)");
  address = 256;
  while (address < chipsize) { // find a blank space
    SerialFlash.read(address, buf, 256);
    if (is_erased(buf, 256)) break;
    address = address + 256;
  }
  if (address >= chipsize) {
    Serial.println("  error, unable to find any blank space!");
    return false;
  }
  for (int i = 0; i < 256; i += 8) {
    create_signature(address + i, sig + i);
  }
  Serial.print("  write 256 bytes at ");
  Serial.println(address);
  Serial.flush();
  SerialFlash.write(address, sig, 256);
  usec = micros();
  if (SerialFlash.ready()) {
    Serial.println("  error, chip did not become busy after write");
    return false;
  }
  SerialFlash.read(0, buf2, 8); // read while busy writing
  while (!SerialFlash.ready()) ; // wait
  usec = micros() - usec;
  Serial.print("  write time was ");
  Serial.print(usec);
  Serial.println(" microseconds.");
  SerialFlash.read(address, buf, 256);
  if (memcmp(buf, sig, 256) != 0) {
    Serial.println("  error writing to flash");
    Serial.print("  Read this: ");
    printbuf(buf, 256);
    Serial.print("  Expected:  ");
    printbuf(sig, 256);
    return false;
  }
  create_signature(0, sig);
  if (memcmp(buf2, sig, 8) != 0) {
    Serial.println("  error, incorrect read while writing");
    Serial.print("  Read this: ");
    printbuf(buf2, 256);
    Serial.print("  Expected:  ");
    printbuf(sig, 256);
    return false;
  }
  Serial.print("  read-while-writing: ");
  printbuf(buf2, 8);
  Serial.println("  test passed, good read while writing");



  // Erase a block and read while erase in progress
  if (chipsize >= 262144 + blocksize + testIncrement) {
    Serial.println();
    Serial.println("Checking Read-While-Erase (Erase Suspend)");
    memset(buf, 0, sizeof(buf));
    memset(sig, 0, sizeof(sig));
    memset(buf2, 0, sizeof(buf2));
    SerialFlash.eraseBlock(262144);
    usec = micros();
    delayMicroseconds(50);
    if (SerialFlash.ready()) {
      Serial.println("  error, chip did not become busy after erase");
      return false;
    }
    SerialFlash.read(0, buf2, 8); // read while busy writing
    while (!SerialFlash.ready()) ; // wait
    usec = micros() - usec;
    Serial.print("  erase time was ");
    Serial.print(usec);
    Serial.println(" microseconds.");
    // read all signatures, check ones in this block got
    // erased, and all the others are still intact
    address = 0;
    first = true;
    while (address < chipsize) {
      SerialFlash.read(address, buf, 8);
      if (address >= 262144 && address < 262144 + blocksize) {
        if (is_erased(buf, 8) == false) {
          Serial.print("  error in erasing at ");
          Serial.println(address);
          Serial.print("  Read this: ");
          printbuf(buf, 8);
          return false;
        }
      } else {
        create_signature(address, sig);
        if (equal_signatures(buf, sig) == false) {
          Serial.print("  error in signature at ");
          Serial.println(address);
          Serial.print("  Read this: ");
          printbuf(buf, 8);
          Serial.print("  Expected:  ");
          printbuf(sig, 8);
          return false;
        }
      }
      if (first) {
        address = address + (testIncrement - 8);
        first = false;
      } else {
        address = address + 8;
        first = true;
      }
    }
    Serial.print("  erase correctly erased ");
    Serial.print(blocksize);
    Serial.println(" bytes");
    // now check if the data we read during erase is good
    create_signature(0, sig);
    if (memcmp(buf2, sig, 8) != 0) {
      Serial.println("  error, incorrect read while erasing");
      Serial.print("  Read this: ");
      printbuf(buf2, 256);
      Serial.print("  Expected:  ");
      printbuf(sig, 256);
      return false;
    }
    Serial.print("  read-while-erasing: ");
    printbuf(buf2, 8);
    Serial.println("  test passed, good read while erasing");

  } else {
    Serial.println("Skip Read-While-Erase, this chip is too small");
  }




  return true;
}


void loop() {
  // do nothing after the test
}

const char * id2chip(const unsigned char *id)
{
  if (id[0] == 0xEF) {
    // Winbond
    if (id[1] == 0x40) {
      if (id[2] == 0x14) return "W25Q80BV";
      if (id[2] == 0x15) return "W25Q16DV";
      if (id[2] == 0x17) return "W25Q64FV";
      if (id[2] == 0x18) return "W25Q128FV";
      if (id[2] == 0x19) return "W25Q256FV";
    }
  }
  if (id[0] == 0x01) {
    // Spansion
    if (id[1] == 0x02) {
      if (id[2] == 0x16) return "S25FL064A";
      if (id[2] == 0x19) return "S25FL256S";
      if (id[2] == 0x20) return "S25FL512S";
    }
    if (id[1] == 0x20) {
      if (id[2] == 0x18) return "S25FL127S";
    }
  }
  if (id[0] == 0xC2) {
    // Macronix
    if (id[1] == 0x20) {
      if (id[2] == 0x18) return "MX25L12805D";
    }
  }
  if (id[0] == 0x20) {
    // Micron
    if (id[1] == 0xBA) {
      if (id[2] == 0x20) return "N25Q512A";
      if (id[2] == 0x21) return "N25Q00AA";
    }
    if (id[1] == 0xBB) {
      if (id[2] == 0x22) return "MT25QL02GC";
    }
  }
  if (id[0] == 0xBF) {
    // SST
    if (id[1] == 0x25) {
      if (id[2] == 0x02) return "SST25WF010";
      if (id[2] == 0x03) return "SST25WF020";
      if (id[2] == 0x04) return "SST25WF040";
      if (id[2] == 0x41) return "SST25VF016B";
      if (id[2] == 0x4A) return "SST25VF032";
    }
    if (id[1] == 0x25) {
      if (id[2] == 0x01) return "SST26VF016";
      if (id[2] == 0x02) return "SST26VF032";
      if (id[2] == 0x43) return "SST26VF064";
    }
  }
  return "(unknown chip)";
}

void print_signature(const unsigned char *data)
{
  Serial.print("data=");
  for (unsigned char i = 0; i < 8; i++) {
    Serial.print(data[i]);
    Serial.print(" ");
  }
  Serial.println();
}

void create_signature(unsigned long address, unsigned char *data)
{
  data[0] = address >> 24;
  data[1] = address >> 16;
  data[2] = address >> 8;
  data[3] = address;
  unsigned long hash = 2166136261ul;
  for (unsigned char i = 0; i < 4; i++) {
    hash ^= data[i];
    hash *= 16777619ul;
  }
  data[4] = hash;
  data[5] = hash >> 8;
  data[6] = hash >> 16;
  data[7] = hash >> 24;
}

bool equal_signatures(const unsigned char *data1, const unsigned char *data2)
{
  for (unsigned char i = 0; i < 8; i++) {
    if (data1[i] != data2[i]) return false;
  }
  return true;
}

bool is_erased(const unsigned char *data, unsigned int len)
{
  while (len > 0) {
    if (*data++ != 255) return false;
    len = len - 1;
  }
  return true;
}


void printbuf(const void *buf, uint32_t len)
{
  const uint8_t *p = (const uint8_t *)buf;
  do {
    unsigned char b = *p++;
    Serial.print(b >> 4, HEX);
    Serial.print(b & 15, HEX);
    //Serial.printf("%02X", *p++);
    Serial.print(" ");
  } while (--len > 0);
  Serial.println();
}

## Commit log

2016-10-06 Add Automatic Reset of ESP-12
    Variants "nodemcu" and "ck"
    [FlexiBoard_FlashESP8266.ino]
2016-10-06 Switch off TFT-Backlight
2016-10-07 READ ME for using ARDUINO on ESP
2016-10-15 SPI-Flash Examples

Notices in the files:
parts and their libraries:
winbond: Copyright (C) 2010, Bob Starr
